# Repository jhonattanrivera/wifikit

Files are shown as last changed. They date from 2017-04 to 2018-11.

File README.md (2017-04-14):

## English

The WiFi + Relays Board Kit is a simple actuator for your home control system. You can control lights, home appliances, irrigation system, whatever you want, just connect the appliance to one of the relays and integrate it to your system.

This kit is based on the ESP8266-01, program it to your needs. Just connect you USB to UART adapter and upload the sketch using the ```FLASH``` and ```RESET``` buttons. In the documentation you will find examples to "talk" with your kit using [HTTP](https://github.com/jorgegarciadev/wifikit/tree/master/HTTP_Server) or [MQTT](https://github.com/jorgegarciadev/wifikit/tree/master/mqtt).

The power supply is integrated in the circuit, so no more USB chargers. The kit also includes several protection measures like a fuse before the power supply and optocouplers isolating the controller from the relay's circuit.

#### Characteristics:

- Dimensions: 920 x 50 x 1.6mm
- Weight: 96g
- Power Supply: 100-240v AC (50/60 Hz)
- Energy consumption at 220 volts:
	- Idle: 0.55W
	- One relay on: 0.95W
	- Two relays on: 1.22W
- Relays:
	- Max current: 10A
	- Max AC voltage: 250/125v (50/60Hz)
	- Max DC voltage: 30v

#### Included:

- 1 x WiFi + Relays Board Kit PCB
- 1 x Fuse holder M205
- 1 x Fuse 5x20
- 1 x Screw terminal DG301 2 positions
- 2 x Screw terminal DG301 3 positions
- 1 x Power Supply HLK-PM01
- 2 x Tact switch SPST-NO 6x6 mm
- 1 x ESP-8266-01 con 1 MegaByte Flash memory
- 1 x 220μF capacitor
- 1 x 100nF capacitor
- 1 x MCP1700-3302E voltage regulator
- 2 x 220Ω resistor
- 2 x 6k8Ω resistor
- 2 x 10kΩ resitor
- 2 x PC817 optocoupler
- 2 x 3mm red LED
- 2 x 1N4002 diode
- 2 x PN2222 transistor
- 2 x SRD-5VDC-SL-C relay
- 1 x 4x1 male pin header
- 1 x 4x2 female pin header

#### Not included:

- UART to USB adapter

## Español

El WiFi + Relays Board Kit es un sencillo actuador para el sistema de control de tu hogar. Puedes controlar luces, electrodomésticos, sistemas de riego, lo que sea, simplemente conecta el aparato a uno de los relés e integralo a tu sistema.

El kit está basado en el ESP8266-01, podrás programarlo para que se adapte a tus necesidades, simplemente conecta tu adaptador Serie a USB y carga tu *sketch* usando los botones ```FLASH``` y ```RESET```. En la documentación encontrarás ejemplos para "hablar" con tu kit mediante HTTP o MQTT.

La fuente de alimentación está integrada en el propio circuito, no más cargadores USB. Además incluye varías medidas de seguridad como fusible previo a la alimentación, y optoacopladores aislando el controlador del circuito de los relés.

#### Características:

- Dimensiones: 920 x 50 x 1,6mm
- Peso: 96g
- Alimentación: 100-240v AC (50/60 Hz)
- Consumos a 220 vóltios:
	- En reposo: 0,55W
	- Un relé conectado: 0,95W
	- Dos relés conectados: 1,22W
- Relés:
	- Corriente máxima: 10A
	- Voltaje máx. alterna: 125/250v (50/60Hz)
	- Voltaje máx. continua: 30v

#### ¿Qué incluye?

- 1 x PCB WiFi + Relays Board Kit
- 1 x Portafusibles M205
- 1 x Fusible 5x20
- 1 x Clema DG301 2 posiciones
- 2 x Clema DG301 3 posiciones
- 1 x Fuente de alimentacion HLK-PM01
- 2 x pulsadores SPST-NO 6x6 mm
- 1 x ESP-8266-01 con 1 MegaByte de memoría Flash
- 1 x Condensador 220μF
- 1 x Condensador 100nF
- 1 x Regulador de tensión MCP1700-3302E
- 2 x Resistencia 220Ω
- 2 x Resistencia 6k8Ω
- 2 x Resistencia 10kΩ
- 2 x Optocoplador PC817
- 2 x LED Rojo 3mm
- 2 x Diodo 1N4002
- 2 x Transistor PN2222
- 2 x Relé SRD-5VDC-SL-C
- 1 x Conector macho 4x1
- 1 x Conector hembra 4x2

#### ¿Qué no incluye?

- Programador Serie a USB

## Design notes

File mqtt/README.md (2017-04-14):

## Español

# Cliente MQTT

Con estos dos sketchs podrás manejar tu *WiFi + Relay Board Kit* mediante MQTT. La carpeta ```simple``` contiene la version sin TLS, y la carpeta ```secure``` contiene la versión con TLS, y soporta la versión ```TLSv1.2```. Están basados en la librería y ejemplos de [Adafruit MQTT](https://github.com/adafruit/Adafruit_MQTT_Library), y depende de ella.

Ambas versiones están configurados para conectarse al *broker* MQTT con credenciales. Cada relé se subscribe a un canal diferente, ```[usuario]/relay_one``` y ```[usuario]/relay_two```, que pueden cambiarse de nombre. El dispositivo se suscribe al canal ```/log``` donde informa de la conexión y cambio de estado de los relés.

Los comandos para encender y apagar los relés son ```ON``` y ```OFF```, y ```STATUS``` para conocer el estado actual del relé.

### Simple

La versión simple necesita los siguientes datos para conectar con el *broker*:

- ```MQTT_SERVER``` dirección del *broker*
- ```MQTT_PORT``` puerto del broker, por definición **1883**
- ```MQTT_USERNAME``` Usuario
- ```MQTT_PASS``` Contraseña

Si el servidor permite conexiones anonimas habrá que modificar las lineas ```28```, ```31``` y ```33```, eliminando cualquier mencion de ```MQTT_USERNAME``` y ```MQTT_PASS```.

Para probar el dispositivo una vez conectado puedes utilizar ```mosquito_pub```:

`mosquitto_pub -h [servidor] -p [puerto] -t '[usuario]/relay_one' -u [usuario] -P [contraseña] -m 'STATUS'`

### Secure

La única diferencia con la versión simple es que esta versión se concta con TLS. Además de los datos necesarios para la versión simple, es necesaria la **huella digital SHA-1** del certificado y ponerla en la variable ```fingerprint```. Solo comprueba si el certificado es correcto, para que setenga la ejecución hay que descomentar la línea ```140```.

Para probar el dispositivo una vez conectado puedes utilizar ```mosquito_pub```:

`mosquitto_pub -h [servidor] -p [puerto] -t '[usuario]/relay_one' -u [usuario] -P [contraseña] -m 'STATUS' --cafile ca.crt`

Siendo ```ca.crt``` la clave publica del certificado del *broker* MQTT.

## English

# MQTT Client

With this Sketches you will be able to control *WiFi + Relay Board Kit* using the MQTT protocol. The ```simple``` folder contains a version without TLS, and the ```secure``` contians the TLS version, that supports ```TLSv1.2```. They are based on [Adafruit MQTT](https://github.com/adafruit/Adafruit_MQTT_Library) library and its examples, and depends on it.

Bothe versions are setup for connecting to the *broker* MQTT using auth. Each relay subscribes to different topics, ```[username]/relay_one``` and ```[username]/relay_two```, that can be changed. Th device suscribes to the topic ```/log``` where it logs the relays state changes and connction info.

The commands for switching on and off the relays are ```ON``` y ```OFF```, and ```STATUS``` to get the relay's state.

### Simple

The simple versión need this data to connect to the broker:

- ```MQTT_SERVER``` broker's address
- ```MQTT_PORT``` broker's port, **1883** by default
- ```MQTT_USERNAME``` Username
- ```MQTT_PASS``` Password

If the server allows anonymous connections you have to edit lines ```28```, ```31``` y ```33```, removinf any mention of ```MQTT_USERNAME``` y ```MQTT_PASS```.

Once the device is connected you can try it with ```mosquito_pub```:

`mosquitto_pub -h [server] -p [port] -t '[username]/relay_one' -u [username] -P [password] -m 'STATUS'`

### Secure

The only difference between the simple and secure versions is that the last one uses TLS. In addition for the data needed for the simple version, You need the cert **SHA-1 fingerprint** and put it in the ```fingerprint``` variable. The Sketch is setup to check if the certificate matches, if you want to stop the execution if the cert doesn't match you have to comment the line ```140```.

Once the device is connected you can try it with ```mosquito_pub```:

`mosquitto_pub -h [server] -p [port] -t '[username]/relay_one' -u [username] -P [password] -m 'STATUS' --cafile ca.crt`

where ```ca.crt``` is the public key for the *broker* MQTT server's cert.

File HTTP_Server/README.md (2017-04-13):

## HTTP Server Sketch

### Español

Con este sketch podrás manejar tu *WiFi + Relay Board Kit* con solicitudes ```GET``` desde cualquier dispositivo. Para ilustrar los ejemplos utilizaré ```curl``` y ```python```.

#### Encender relé

Para encender los relés utilizaremos la ruta ```/on``` con el parámetro ```relay``` y el número de relé a encender:

Con ```curl```:
```
curl "http://192.168.1.40/on" --data 'relay=1'
```
Con ```python```:
```
import requets

r = requests.get("http://192.168.1.40" + "/on", params = {'relay': 1})

```

#### Apagar relé

Para apagar los relés utilizaremos la ruta ```/off``` con el parámetro ```relay``` y el número de relé a apagar:

Con ```curl```:
```
curl "http://192.168.1.40/off" --data 'relay=2'
```
Con ```python```:
```
import requets

r = requests.get("http://192.168.1.40" + "/off", params = {'relay': 2})

```

#### Estado de los relés

Para conocer el estado actual de un rele utilizaremos la ruta ```/status``` y el parámetro ```relay``` con el número del relé a consultar:

Con ```curl```:
```
curl "http://192.168.1.40/status" --data 'relay=2'
```
Con ```python```:
```
import requets

r = requests.get("http://192.168.1.40" + "/status", params = {'relay': 2})
print(r.text)

```

#### Opciones

El sketch viene configurado para usar una IP estática, se puede cambiar a una dinámica comentando las líneas ```12-14``` y ```84```.
```mDNS``` está desactivado, para configurarlo es necesario descomentar las líneas ```4``` y ```98-100```, el dispositivo tiene el nombre "kit", para cambiarlo hay que modificar ```mdns.begin("kit", WiFi.localIP())``` en la línea ```98```.

En la carpeta ```HTTP_Server+Panel``` hay una versión de este mismo *sketch* con un panel hospedado en el propio ESP8266 (exceptuando imágenes y archivos javascript y estilos). El panel consta de dos interruptores, uno para cada relé. Para acceder al panel abre un navegador en cualquier dispositivo con acceso a internet e introduce la IP del dispositivo o, si tu sistema operativo soporta Bonjour o Avahi, escribiendo ```kit.local```.

### English

With this sketch you will be able to control your *WiFi + Relay Board Kit* using ```GET``` requests from any device. For the example I'm going to use ```curl``` and ```python```.

#### Switch On Relay

For switching on one of the relay use the path ```/on``` with the parameter ```relay``` and the relay number:

With ```curl```:
```
curl "http://192.168.1.40/on" --data 'relay=1'
```
With ```python```:
```
import requets

r = requests.get("http://192.168.1.40" + "/on", params = {'relay': 1})

```

#### Switch Off Relay

For switching on one of the relay use the path ```/off``` with the parameter ```relay``` and the relay number:

With ```curl```:
```
curl "http://192.168.1.40/off" --data 'relay=2'
```
With ```python```:
```
import requets

r = requests.get("http://192.168.1.40" + "/off", params = {'relay': 2})

```

#### Relay State

If you want to know the actual state of one of the relays use the path ```/status``` and the parameter ```relay``` with the number of the relay:

With ```curl```:
```
curl "http://192.168.1.40/status" --data 'relay=2'
```
With ```python```:
```
import requets

r = requests.get("http://192.168.1.40" + "/status", params = {'relay': 2})
print(r.text)

```

#### Options

This sketch is configured with an static IP, you can change it to dinamic commenting the lines```12-14``` and ```84```.
```mDNS``` is disabled, to enable it just uncomment lines ```4``` y ```98-100```, the device is named "kit", to change it modify ```mdns.begin("kit", WiFi.localIP())``` in line ```98```.

There is a version of this same sketch with a control panel hosted in the ESP8266 (but the images, and javascript and styles files). This panel has two switch, one for each relay. To access this panel open a browser in any device with internet access an open the device IP or, if your operating system support Bonjour or Avahi, open ```kit.local```.

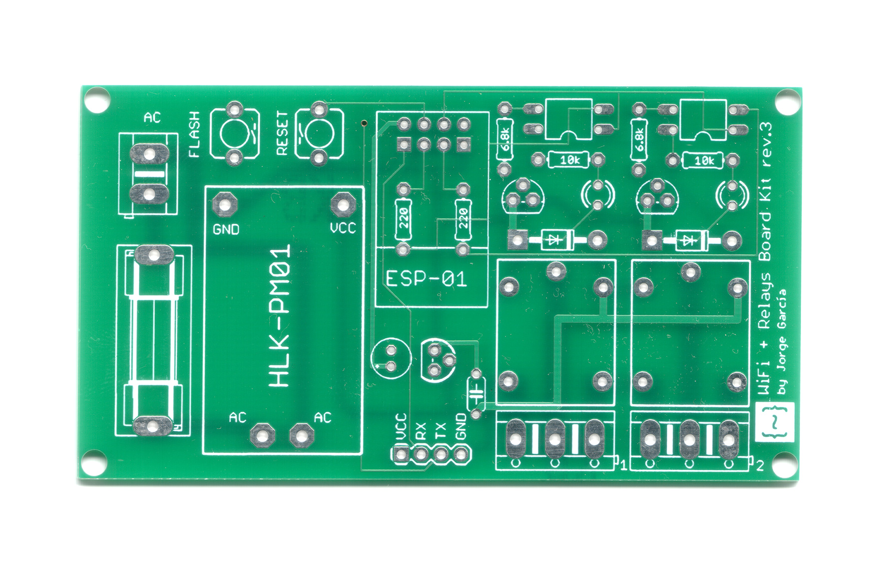
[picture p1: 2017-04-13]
pictures/PCB.jpg

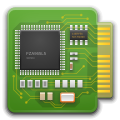
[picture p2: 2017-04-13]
HTTP_Server/HTTP_Server+Panel/server/img/ios-desktop.png

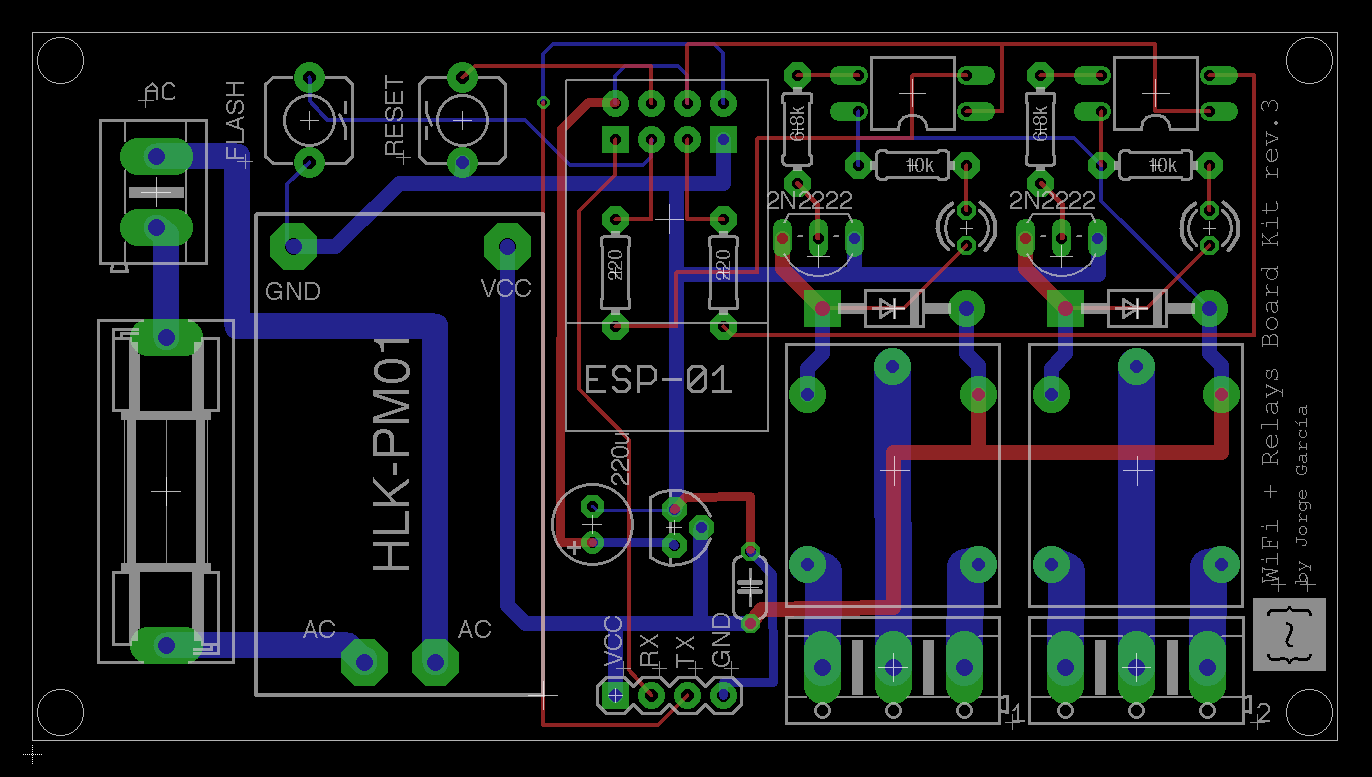
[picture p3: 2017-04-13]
pictures/PCB-Eagle.png

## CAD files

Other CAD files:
schematics/3d-model.skp

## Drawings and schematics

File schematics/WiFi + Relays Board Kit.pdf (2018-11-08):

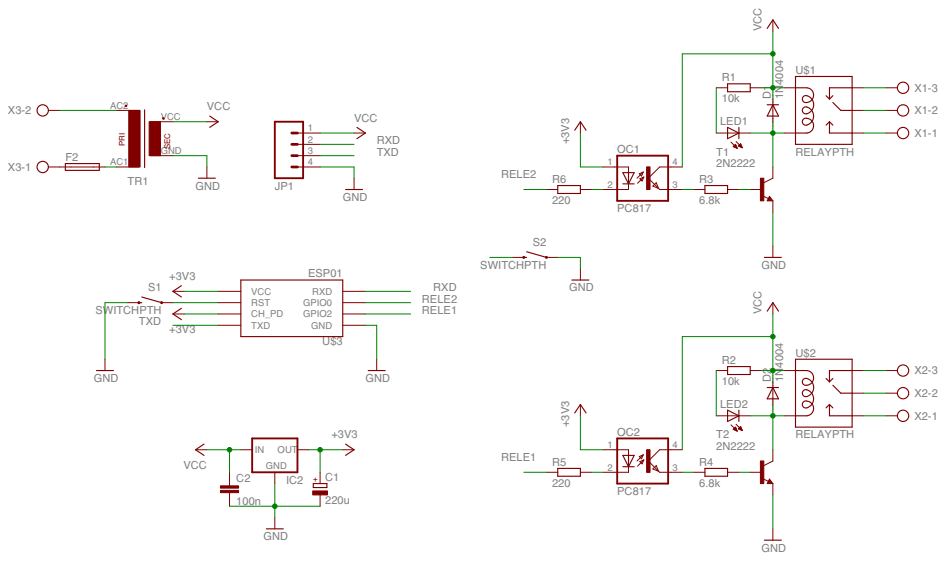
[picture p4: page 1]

SpiceOrder 1 SpiceOrder 2 SpiceOrder 1 SpiceOrder 2 RELAYPTH RELAYPTH 10k 10k 1N4004 1N4004 VCC VCC GND GND VCC GND GND GNDVCC SWITCHPTH 2N2222 2N2222 PC817 PC817 6.8k 6.8k +3V3 +3V3 +3V3 +3V3 +3V3 GND 220 220 100n 220u SWITCHPTH VCC GND GND U$1 U$2 GND GPIO2 GPIO0 RXD TXD CH_PD RST VCC U$3 ESP01 R1 R2 D1 D2 LED1 LED2 X1-1 X1-2 X1-3 X2-1 X2-2 X2-3 S1 T1 OC2 T2 12 34 OC1 12 34 R3 R5 R4 TR1 R6 AC1 AC2 VCC GND X3-1 X3-2 C2 C1 S2 JP1 1234 F2 IC2 GND IN OUT RELE2 RELE2 RELE1 RELE1 RXD RXD TXD TXD PRI SEC +

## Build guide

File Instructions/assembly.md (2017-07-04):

## Español

Esta guía se limita a los componentes que pueden producir alguna duda a la hora de soldarlos: los transistores, los LED, el regulador de tensión y el condensador electrolítico. Se omiten el resto por su naturaleza o por las indicaciones en la propia placa (serigrafiado).

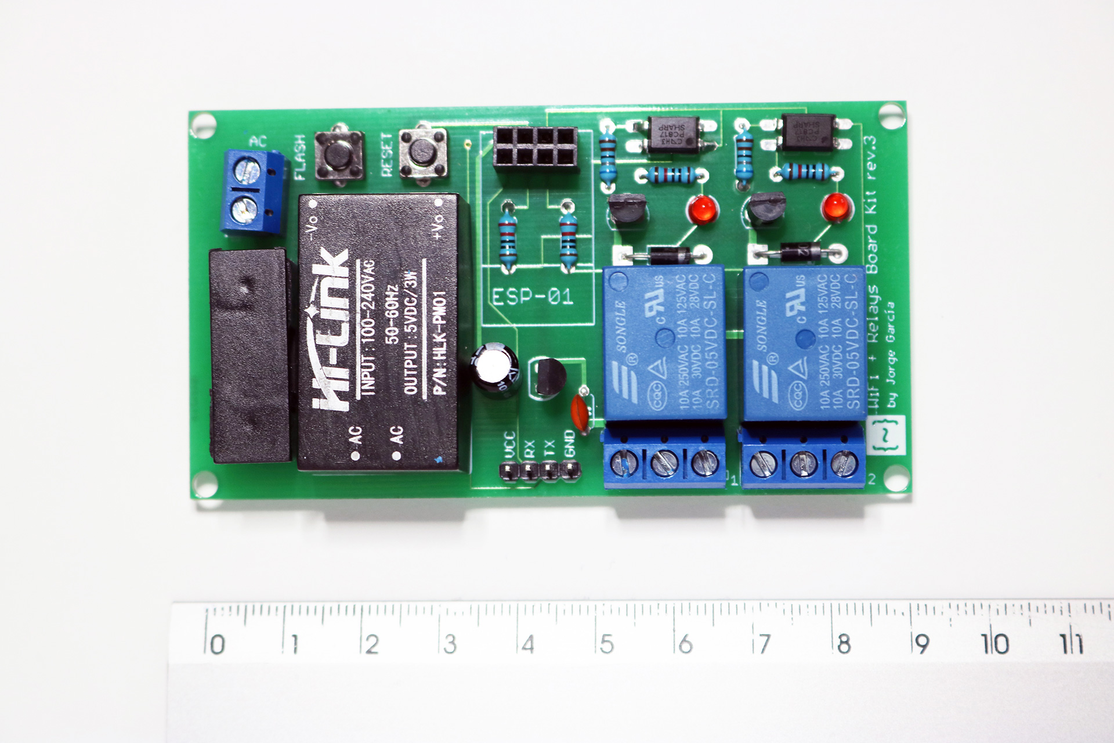
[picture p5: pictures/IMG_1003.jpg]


### Transistores

Los transistores son unos PN2222, con encapsulado TO-92 y patillas anchas. No deben confundirse con el regulador de tensión MCP1700, también con encapsulado TO-92 pero patilla estrecha.

Al diseñar la placa utilicé un modelo que luego me fué imposible encontrar, por eso mismo si te fijas en la foto de más arriba no coinciden el serigrafiado con como está soldados los transistores.

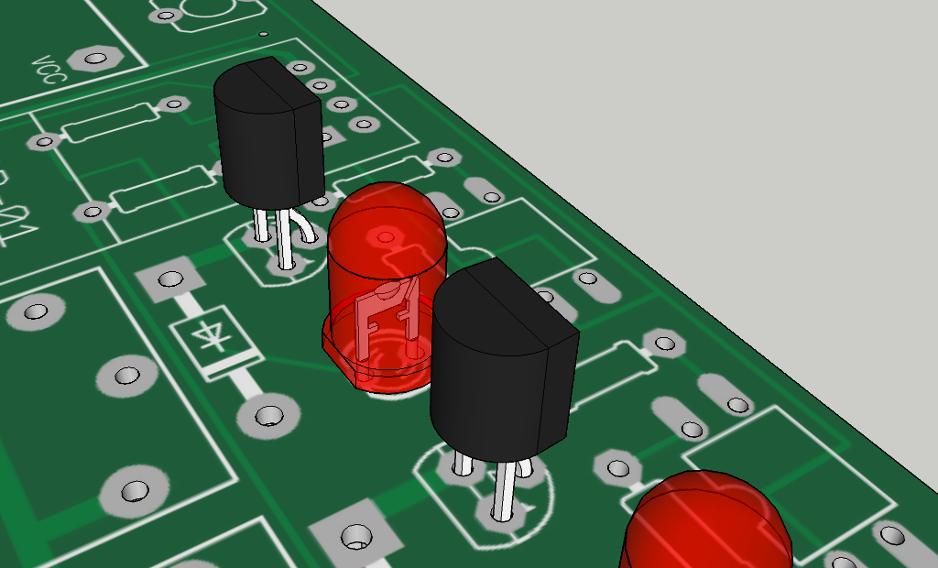
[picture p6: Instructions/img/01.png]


Como se puede ver en el modelo 3d el lado plano del transitor queda del lado de los optocopladores.

### LED

Se trata de dos LED rojos de 3mm. Los LED tienen en la base una zona plana y una patilla más corta que coinciden con el polo negativo del LED. Éstas deben quedar del lado del los relés.

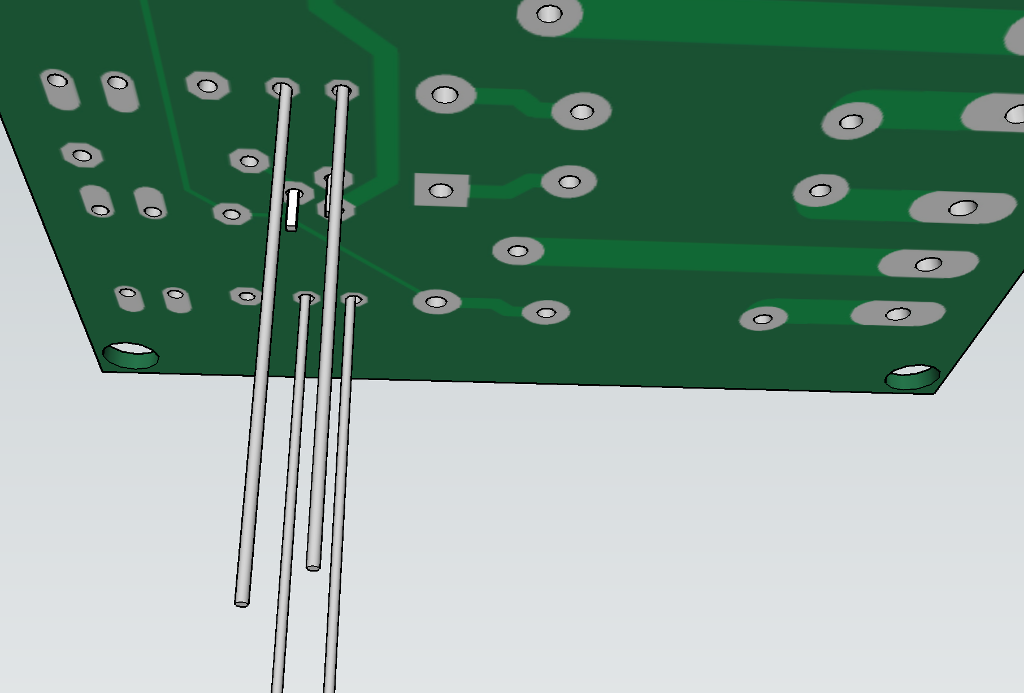
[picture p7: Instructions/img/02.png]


### Condensador electrolítico y regulador de tensión

El condensador electrolítico de 220μF tiene una franja blanca y una patilla más corta que coinciden con el polo negativo del condensador.

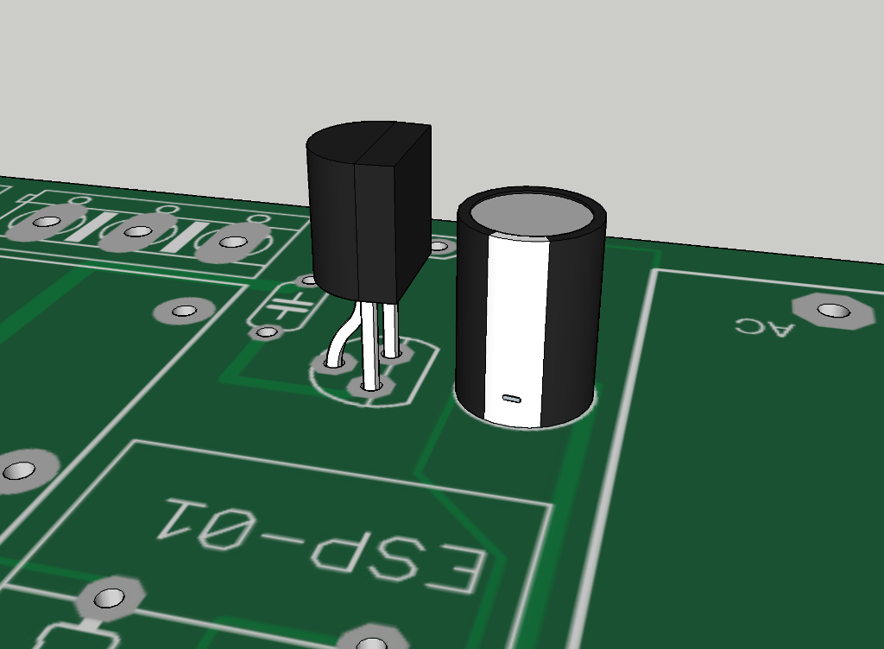
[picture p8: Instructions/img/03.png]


Estos deben ir del lado del ESP-8266-01.

El regulador de tensión es un MCP1700-3302E con empaquetado TO-92 con patillas estrecha, no confundir con los transistores PN2222 de patillas anchas. El regulador sigue el serigrafiado.

## English

This guide is just for the components that could mislead the user when soldering: transistors, LED, voltage regulator and electrolytic capacitor. The other ones are omited because of their nature or because the indications on the board's silk.



### Transistors

The transistors are PN2222, with TO-92 packaging and wide pins. Don't mistake them with the voltage regulator MCP1700, with TO-92 packaging too but narrow pins.

I couldn't find the model used in the design for the transistors, You can notice in the picture that the position of the transistors doesn't match the board's silk.



As you can see in the 3d model the flat side of the transistor is facing the optocouplers.

### LED

There are two 3mm red LED. They have a flat side in their bases and a shorter pin that tell where ground is. Those should face the relays.



### Electrolytic capacitor and voltage regulator

The 220μF electrolytic capacitor has a white bar and a shorter pin that coincide with ground.



Those should face the ESP-8266-01.

The voltage regulator is a MCP1700-3302E with TO-92 packaging and narrow pins, don't mistake it with the transistors PN2222, with TO-92 packaging too and wide pins. In this case the component follow the board's silk.

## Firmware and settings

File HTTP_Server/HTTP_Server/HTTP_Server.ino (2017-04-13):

#include <ESP8266WiFi.h>
#include <WiFiClient.h>
#include <ESP8266WebServer.h>
// #include <ESP8266mDNS.h>


// SSID Configuration
const char* ssid = ". . .";
const char* password = ". . .";

// static ip configuration
IPAddress ip(192,168,1,40);
IPAddress gateway(192,168,1,1);
IPAddress subnet(255,255,255,0);

const char* response = "{\"status\": %d, \"code\": %d}";
char buffer[26];

// MDNSResponder mdns;

ESP8266WebServer server(80);

const int R1 = 0;
const int R2 = 2;





void handleNotFound(){
  String message = "Resource not found\n\n";
  message += "URI: ";
  message += server.uri();
  message += "\nMethod: ";
  message += (server.method() == HTTP_GET)?"GET":"POST";
  message += "\nArguments: ";
  message += server.args();
  message += "\n";
  for (uint8_t i=0; i<server.args(); i++){
    message += " " + server.argName(i) + ": " + server.arg(i) + "\n";
  }
  server.send(404, "text/plain", message);
}

void handleRelay(int relay, int level) {
  // change the state of the relay given the relay number and the level
  digitalWrite(relay, level);

  level ? level = 0 : level = 1;

  sprintf(buffer, response, level , 200);
  server.send(200, "application/json", buffer);
}

void statusRelay(int relay){
  // returns the status of the relay given the relay number
  int status;
  status = digitalRead(relay);

  status ? status = 0 : status = 1;

  sprintf(buffer, response, status, 200);
  server.send(200, "application/json", buffer);
}

void handleErr() {
  // handle wrong requests
  sprintf(buffer, response, -1, 401);
  server.send(401, "application/json", buffer);
}
 
void setup(void){
  Serial.begin(115200);

  Serial.println("Hello!");
  digitalWrite(R1, HIGH);
  digitalWrite(R2, HIGH);

  pinMode(R1, OUTPUT);
  pinMode(R2, OUTPUT);

  WiFi.mode(WIFI_STA);
  WiFi.begin(ssid, password);
  WiFi.config(ip, gateway, subnet);
  Serial.println("");

  // Wait for connection
  while (WiFi.status() != WL_CONNECTED) {
    delay(500);
    Serial.print(".");
  }
  Serial.println("");
  Serial.print("Connected to ");
  Serial.println(ssid);
  Serial.print("IP address: ");
  Serial.println(WiFi.localIP());

  // if (mdns.begin("kit", WiFi.localIP())) {
  //   Serial.println("MDNS initialized.");
  // }


  server.on("/on", [](){
    if(server.method() == HTTP_GET){
      int relay = server.arg("relay").toInt();
      (relay == 1) ? handleRelay(R1, LOW): (relay == 2) ? handleRelay(R2, LOW) : handleErr();
      Serial.println(buffer);
    }
    else{
      handleErr();
    }
  });

  server.on("/off", [](){
    if(server.method() == HTTP_GET){
      int relay = server.arg("relay").toInt();
      (relay == 1) ? handleRelay(R1, HIGH): (relay == 2) ? handleRelay(R2, HIGH) : handleErr();
      Serial.println(buffer);
    }
    else{
      handleErr();
    }
  });


  server.on("/status", [](){
    if(server.method() == HTTP_GET){
      int relay = server.arg("relay").toInt();
      (relay == 1) ? statusRelay(R1): (relay == 2) ? statusRelay(R2) : handleErr();
      Serial.println(buffer);
    }
    else{
      handleErr();
    }
  });

  server.onNotFound(handleNotFound);
  
  server.begin();
  Serial.println("HTTP server initialized.");
}
 
void loop(void){
  server.handleClient();
} 

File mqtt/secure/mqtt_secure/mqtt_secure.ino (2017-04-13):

#include <ESP8266WiFi.h>
#include <WiFiClientSecure.h>
#include "Adafruit_MQTT.h"
#include "Adafruit_MQTT_Client.h"
// WLAN Setup
#define WLAN_SSID       ". . ."
#define WLAN_PASS       ". . ."

// MQTT setup
#define MQTT_SERVER      ". . ."
#define MQTT_PORT        8883
#define MQTT_USERNAME    ". . ."
#define MQTT_PASS        ". . ."

const char* response = "{\"status\": %d, \"code\": %d}";
const int R1 = 12;
const int R2 = 13;
char buffer[50];

const char* fingerprint = "00 7A 11 3D 18 8D 31 2F 7A 92 1B 39 B2 A7 89 5C E9 6D 34 DC";

String commands[] = {"ON", "OFF", "STATUS"};

WiFiClientSecure client;

Adafruit_MQTT_Client mqtt(&client, MQTT_SERVER, MQTT_PORT, MQTT_USERNAME, MQTT_PASS);


Adafruit_MQTT_Subscribe relay_one = Adafruit_MQTT_Subscribe(&mqtt, MQTT_USERNAME "/relay_one", MQTT_QOS_1);

Adafruit_MQTT_Subscribe relay_two = Adafruit_MQTT_Subscribe(&mqtt, MQTT_USERNAME "/relay_two", MQTT_QOS_1);

Adafruit_MQTT_Publish responder = Adafruit_MQTT_Publish(&mqtt, "/log");


void handleRelay(int relay, char *data) {
  int level;
  String cmd = data;
  if (cmd == commands[0]){
    level = LOW;
    digitalWrite(relay, level);
  }
  else if (cmd == commands[1]){
    level = HIGH;
    digitalWrite(relay, level);
  }
  else if (cmd == commands[2]){
    level = digitalRead(relay);
  }
  else {
    level = -1;
  }
  level == -1 ? level = -1 : level ? level = 0 : level = 1;


  sprintf(buffer, response, level , 200);
  Serial.println(buffer);
  responder.publish(buffer);
}

void relayCallbackOne(char *data, uint16_t len){
  Serial.print("Relay 1 received: ");
  Serial.println(data);
  handleRelay(R1, data);
}

void relayCallbackTwo(char *data, uint16_t len){
  Serial.print("Relay 2 received: ");
  Serial.println(data);
  handleRelay(R2, data);
}


void MQTT_connect() {
  int8_t ret;

  // Stop if already connected.
  if (mqtt.connected()) {
    return;
  }

  Serial.print("Connecting to MQTT... ");

  uint8_t retries = 3;
  while ((ret = mqtt.connect()) != 0) { // connect will return 0 for connected
       Serial.println(mqtt.connectErrorString(ret));
       Serial.println("Retrying MQTT connection in 10 seconds...");
       mqtt.disconnect();
       delay(10000);  // wait 10 seconds
       retries--;
       if (retries == 0) {
         // basically die and wait for WDT to reset me
         while (1);
       }
  }
  Serial.println("MQTT Connected!");
}

void setup() {
  Serial.begin(115200);
  delay(10);

  Serial.println(F("Hello!"));
  digitalWrite(R1, HIGH);
  digitalWrite(R2, HIGH);

  pinMode(R1, OUTPUT);
  pinMode(R2, OUTPUT);

  // Connect to WiFi access point.
  Serial.println(); Serial.println();
  Serial.print("Connecting to ");
  Serial.println(WLAN_SSID);

  WiFi.mode(WIFI_STA);
  WiFi.begin(WLAN_SSID, WLAN_PASS);
  Serial.println("");

  // Wait for connection
  while (WiFi.status() != WL_CONNECTED) {
    delay(500);
    Serial.print(".");
  }
  Serial.println("");
  Serial.print("Connected to ");
  Serial.println(WLAN_SSID);
  Serial.print("IP address: ");
  Serial.println(WiFi.localIP());

  if (client.verify(fingerprint, MQTT_SERVER)) {
    Serial.println("certificate matches");
  } else {
    Serial.println("certificate doesn't match");
    // while (1);
  }

  relay_one.setCallback(relayCallbackOne);
  relay_two.setCallback(relayCallbackTwo);
  
  // Setup MQTT subscription for time feed.
  mqtt.subscribe(&relay_one);
  mqtt.subscribe(&relay_two);

}

void loop() {
  // Ensure the connection to the MQTT server is alive (this will make the first
  // connection and automatically reconnect when disconnected).  See the MQTT_connect
  // function definition further below.
  MQTT_connect();

  // this is our 'wait for incoming subscription packets and callback em' busy subloop
  // try to spend your time here:
  mqtt.processPackets(10000);
  
  // ping the server to keep the mqtt connection alive
  // NOT required if you are publishing once every KEEPALIVE seconds
  
  if(! mqtt.ping()) {
    mqtt.disconnect();
  }
}

// Function to connect and reconnect as necessary to the MQTT server.
// Should be called in the loop function and it will take care if connecting.

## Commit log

2017-07-11 3d model
    [3d-model.skp]
2018-11-08 schematic in pdf file
